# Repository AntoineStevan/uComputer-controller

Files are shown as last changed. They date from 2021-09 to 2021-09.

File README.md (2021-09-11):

# A simple game controller for the µ-C1 computer.
This repo and project contain all the files used to create the game controller for the µ-C1 computer.

## Table Of Content.
 - [0  ](https://github.com/AntoineStevan/uComputer-controller/tree/main/#0-prerequisites-toc)  Prerequisites.
 - [1  ](https://github.com/AntoineStevan/uComputer-controller/tree/main/#1-some-images-toc) Some images.
 - [2  ](https://github.com/AntoineStevan/uComputer-controller/tree/main/#2-open-in-kicad-toc)  Open in KiCAD.
 - [2.1](https://github.com/AntoineStevan/uComputer-controller/tree/main/#21-install-kicad-toc) Install KiCAD.
 - [2.2](https://github.com/AntoineStevan/uComputer-controller/tree/main/#22-use-kicad-toc)     Use KiCAD.

## 0. Prerequisites. [[toc](https://github.com/AntoineStevan/uComputer-controller/tree/main/#table-of-content)]
Some schematics and footprints are custom.  
One can find them [here](https://github.com/AntoineStevan/kicad-libraries).

## 1 Some images. [[toc](https://github.com/AntoineStevan/uComputer-controller/tree/main/#table-of-content)]
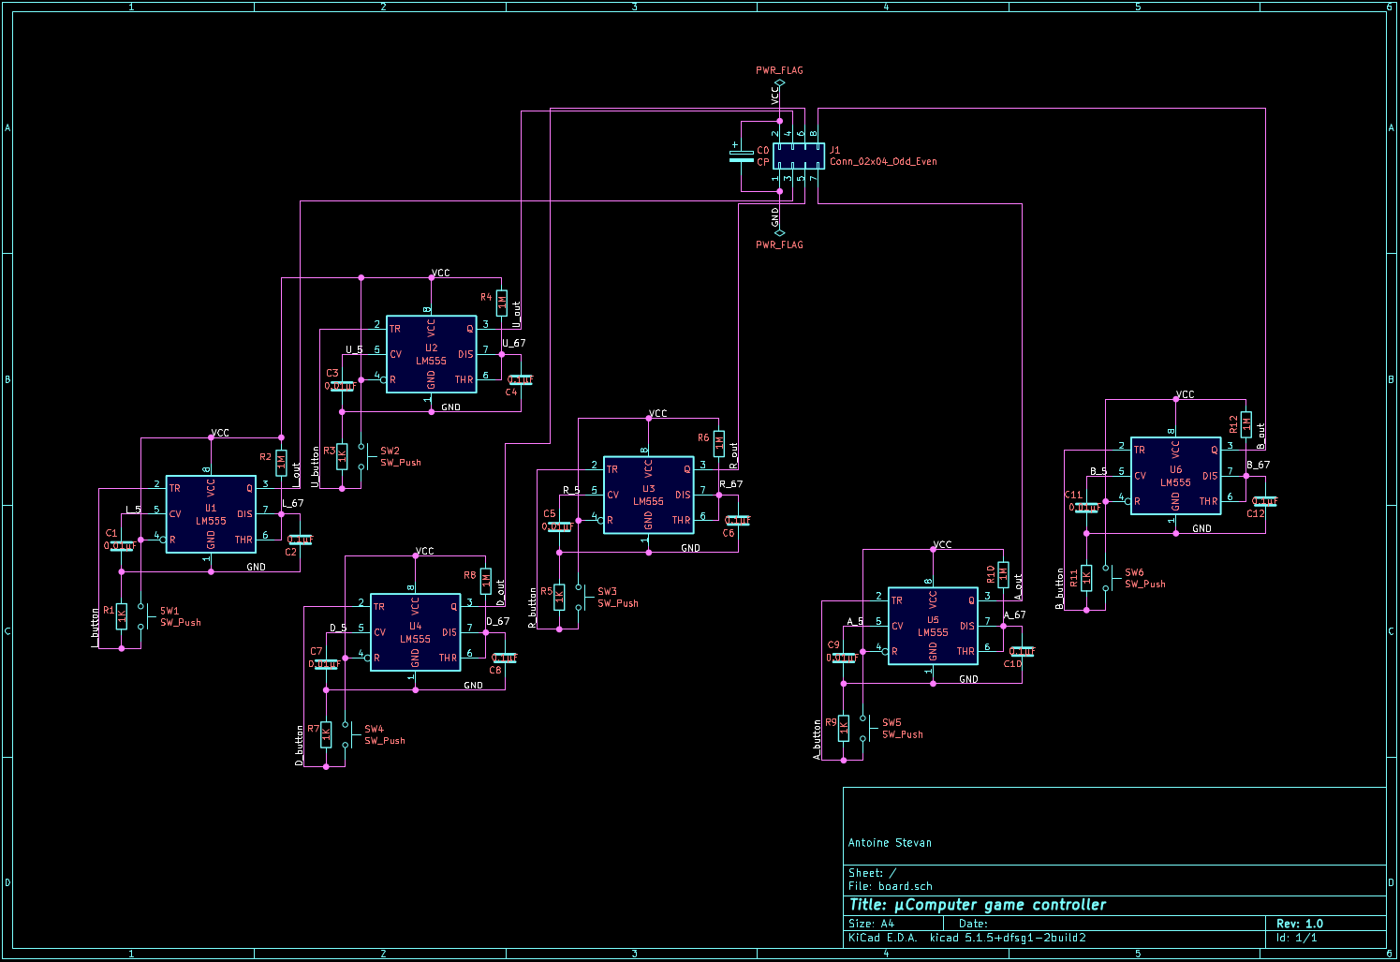
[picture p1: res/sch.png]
||
|:--:|
| *preview of the schematics.* |

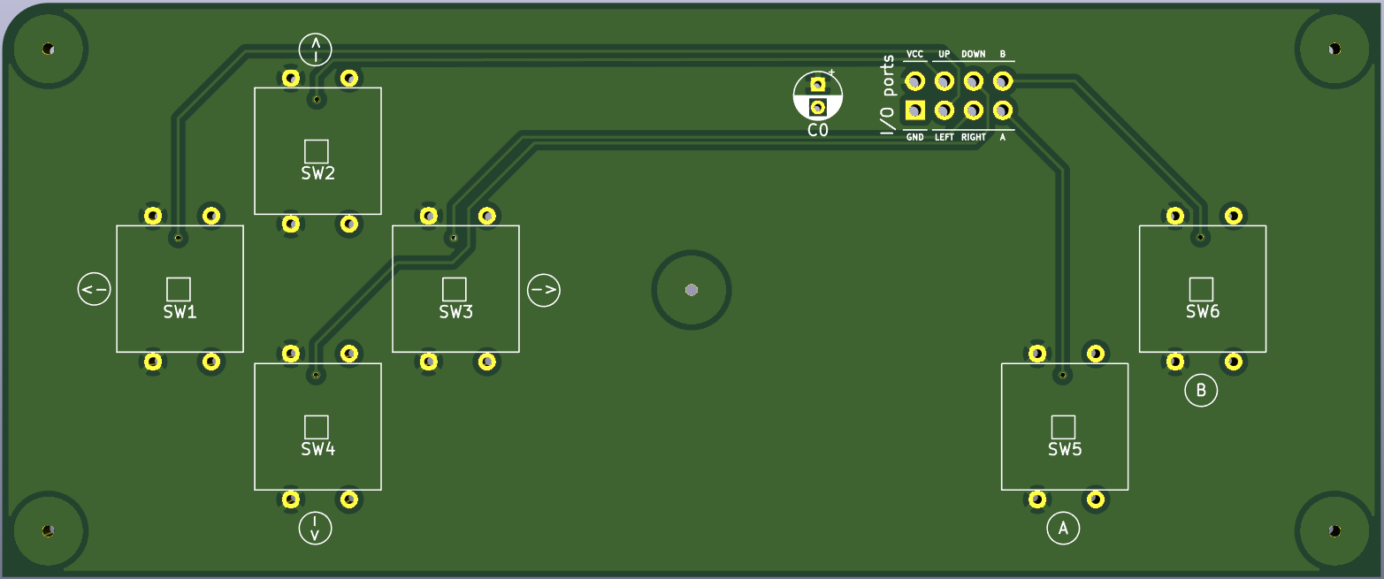
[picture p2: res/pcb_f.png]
||
|:--:|
| *preview of the pcb design (front side).* |

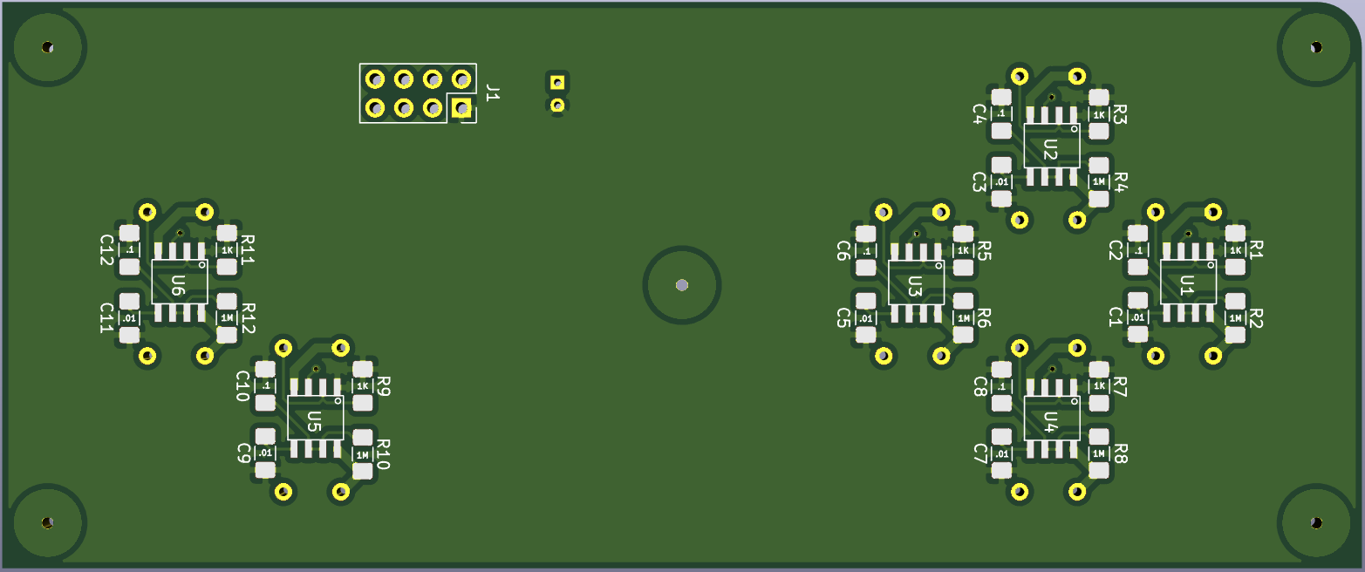
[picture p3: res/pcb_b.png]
||
|:--:|
| *preview of the pcb design (back side).* |

## 2. Open in KiCAD. [[toc](https://github.com/AntoineStevan/uComputer-controller/tree/main/#table-of-content)]
This project has been designed under KiCAD, which is, according to their official website, *an open-source software tool for the creation of electronic schematic diagrams and PCB artwork.*  
All usefull official documentation can be found on the website of the Kicad software [here](https://www.kicad.org/).  
Furthermore, parts have been ordered by [Mouser](https://www.mouser.fr/) and PCBs have been manufactured by [JLCPCB](https://jlcpcb.com/).

### 2.1. Install KiCAD. [[toc](https://github.com/AntoineStevan/uComputer-controller/tree/main/#table-of-content)]
Official KiCAD material can be found [here](https://docs.kicad.org/5.1/en/getting_started_in_kicad/getting_started_in_kicad.html).  
Further specific material for Linux users can be found [here](https://doc.ubuntu-fr.org/kicad).

### 2.2. Use KiCAD. [[toc](https://github.com/AntoineStevan/uComputer-controller/tree/main/#table-of-content)]
The KiCAD team provides plenty of documentation and examples on their official website [here](https://docs.kicad.org/).  
The Internet is also full of great quality tutorials on many topics concerning KiCAD software and schematics/PCB design in general.

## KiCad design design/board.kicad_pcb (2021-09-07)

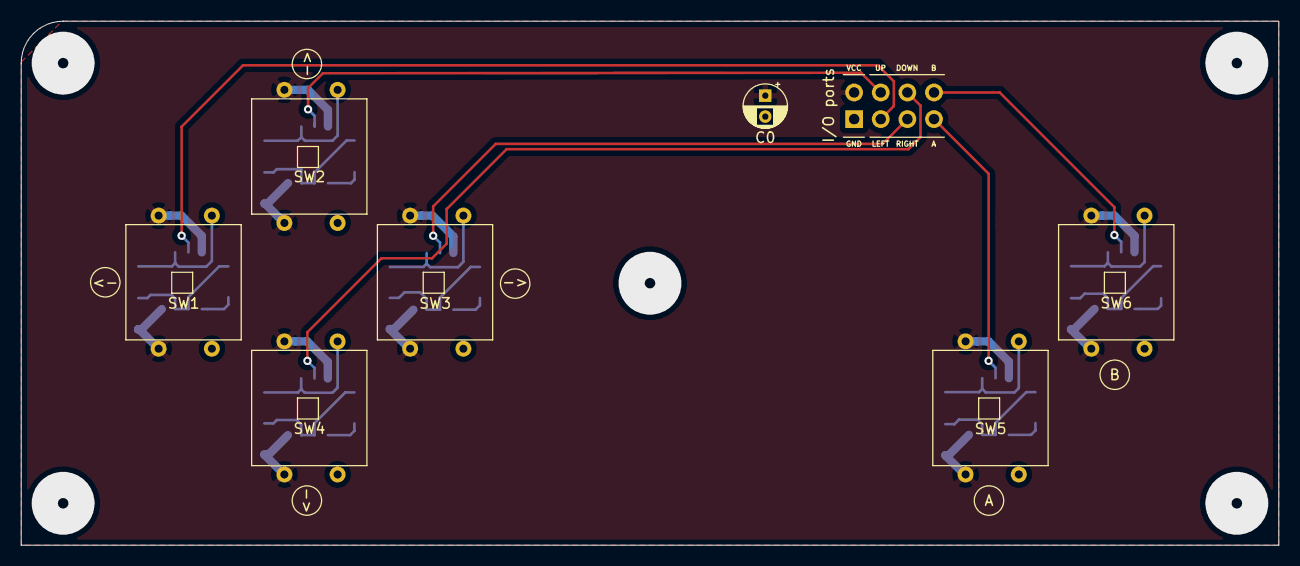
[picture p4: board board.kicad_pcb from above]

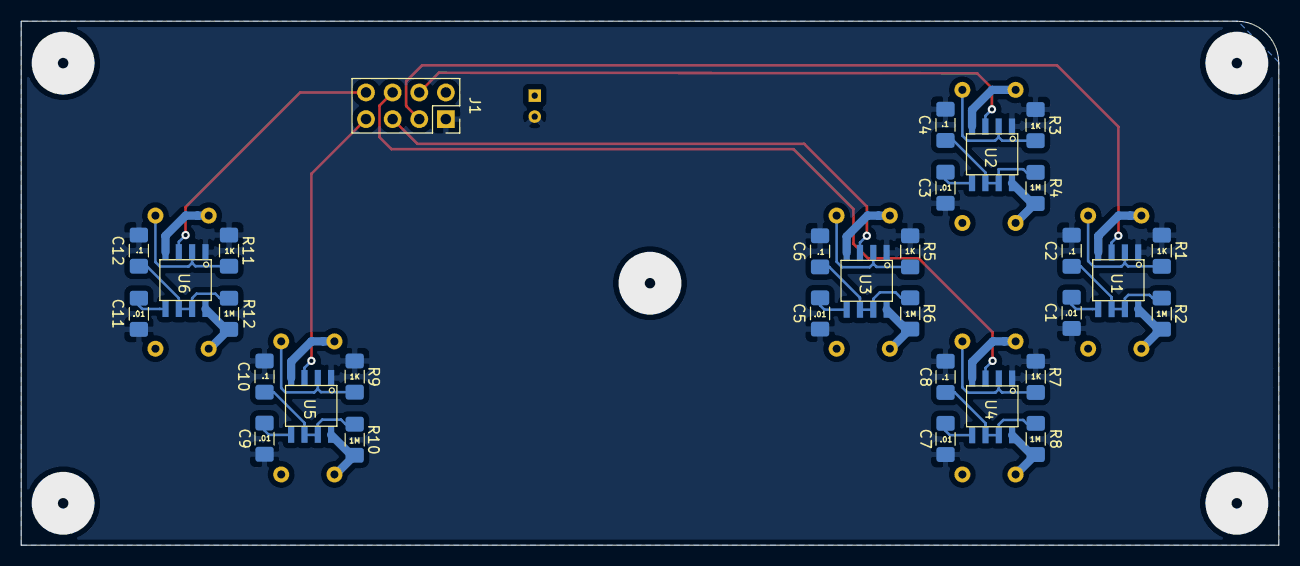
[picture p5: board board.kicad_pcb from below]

Board: 2 copper layers, 120.0 x 50.0 mm, 38 parts (31 on the bottom side), 26 nets.

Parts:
C0: CP; CP_Radial_D4.0mm_P2.00mm
C1, C3, C5, C7, C9, C11: 0.01µF; C_1206_3216Metric_Pad1.42x1.75mm_HandSolder
C2, C4, C6, C8, C10, C12: 0.1µF; C_1206_3216Metric_Pad1.42x1.75mm_HandSolder
J1: Conn_02x04_Odd_Even; PinSocket_2x04_P2.54mm_Vertical
R1, R3, R5, R7, R9, R11: 1K; R_1206_3216Metric_Pad1.42x1.75mm_HandSolder
R2, R4, R6, R8, R10, R12: 1M; R_1206_3216Metric_Pad1.42x1.75mm_HandSolder
SW1, SW2, SW3, SW4, SW5, SW6: SW_Push; pushbutton_3x6
U1, U2, U3, U4, U5, U6: LM555; LM555_SOIC-8_p1.27_l1.55_w0.6_W5.4

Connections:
/A_5: C9.2, U5.5
/A_67: C10.2, R10.2, U5.6, U5.7
/A_button: R9.2, SW5.2, U5.2
/A_out: J1.7, U5.3
/B_5: C11.2, U6.5
/B_67: C12.2, R12.2, U6.6, U6.7
/B_button: R11.2, SW6.2, U6.2
/B_out: J1.8, U6.3
/D_5: C7.2, U4.5
/D_67: C8.2, R8.2, U4.6, U4.7
/D_button: R7.2, SW4.2, U4.2
/D_out: J1.6, U4.3
/GND: C0.2, C1.1, C2.1, C3.1, C4.1, C5.1, C6.1, C7.1, C8.1, C9.1, C10.1, C11.1, C12.1, J1.1, R1.1, R3.1, R5.1, R7.1, R9.1, R11.1, U1.1, U2.1, U3.1, U4.1, U5.1, U6.1
/L_5: C1.2, U1.5
/L_67: C2.2, R2.2, U1.6, U1.7
/L_button: R1.2, SW1.2, U1.2
/L_out: J1.3, U1.3
/R_5: C5.2, U3.5
/R_67: C6.2, R6.2, U3.6, U3.7
/R_button: R5.2, SW3.2, U3.2
/R_out: J1.5, U3.3
/U_5: C3.2, U2.5
/U_67: C4.2, R4.2, U2.6, U2.7
/U_button: R3.2, SW2.2, U2.2
/U_out: J1.4, U2.3
/VCC: C0.1, J1.2, R2.1, R4.1, R6.1, R8.1, R10.1, R12.1, SW1.1, SW1.3, SW2.1, SW2.3, SW3.1, SW3.3, SW4.1, SW4.3, SW5.1, SW5.3, SW6.1, SW6.3, U1.4, U1.8, U2.4, U2.8, U3.4, U3.8, U4.4, U4.8, U5.4, U5.8, U6.4, U6.8

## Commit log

2021-09-06 First schematics.
    [board.kicad_pcb, board.sch]
2021-09-06 Components draft layout + minor changes.
    [board.kicad_pcb, board.sch]
2021-09-07 PCB layout.
    [board.kicad_pcb, board.sch]
2021-09-07 v1 of the controller done.
    [board.kicad_pcb]
2021-09-07 New decoupling capacitor + mounting holes + image update.
    [board.kicad_pcb, board.sch]
2021-09-07 Correct schematics for the README.md file.
2021-09-07 Minor changes.
    [board.kicad_pcb]
2021-09-11 Link to kicad-libraries + futher explainations.
